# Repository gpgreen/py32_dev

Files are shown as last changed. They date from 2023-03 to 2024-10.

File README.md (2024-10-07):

# py32_dev

KiCad design for a ARM Cortex-M0+ development board. The MCU is a Puya
PY32 Series. The specific part is PY032F030K18T6. This can run at a
maximum of 48 MHz, and has 8 kbyte SRAM and 64 kbyte Flash. A USB C
connector provides 5V power only to the development board. The board
must be programmed with a debugger. External crystals are laid out for
the MCU to use a 32.768 kHz low speed crystal or a 24 MHz high speed
crystal. There is an onboard LDO that provides 500mA of power at
3.3V. A resettable fuse protects the USB port from a short. There is
an LED and push button connected to 2 of the GPIO pins. The value of
the BOOT0 pin can be set to ground or 3.3V permanently via the solder
bridge. A jumper can be used on the pin rails in lieue of the solder
bridge. All available GPIO pins are routed to the 2 18pin headers.

## Changes

- Rev B
  Moved resettable fuse away from USB C connector, giving more room to resolder
  connector pins.

- Rev A
  Original

## Firmware

Example firmware that blinks the LED. When the user pushbutton is pressed,
the frequency of the LED blink will change.

https://github.com/gpgreen/py32-dev-blink

## Boot configuration

To boot from main flash [0x0800_0000]
  Connect J2-4 to J2-5 (or) solder JP5-1 to center post

To boot from System mem [0x1FFF_0000], or Embedded SRAM [0x2000_0000]
  Connect J2-4 to J2-3 (or) solder JP6-3 to center post

There is an embedded boot loader, programmed in production, in the system memory
block. See the reference manual 3.6.2.

## PIN JUMPER SIGNAL ASSIGNMENT
```
                    +-----+
            +--------------------+
            |J3     |     |    J2|
        VDD-|1      +-----+     1|-GND
        GND-|2                  2|-GND
       +3.3-|3                  3|-+3.3
[RESET] PF2-|4                  4|-PF4 [BOOT0_PRE]
[SWCLK]PA14-|5                  5|-GND
[SWDIO]PA13-|6                  6|-GND
        GND-|7       RST        7|-GND
        PF3-|8       +-+        8|-GND
        PA0-|9       |O|        9|-GND
        PA1-|10      +-+       10|-PB7
        PA2-|11                11|-PB6
        PA3-|12                12|-PB5
        PA4-|13                13|-PB4
        PA6-|14                14|-PB3
        PA6-|15   UPB          15|-PA15
        PA7-|16   +-+          16|-PA12 [USER LED - GREEN]
        PB0-|17   |O|          17|-PA11 [USER PUSHBUTTON]
        PB1-|18   +-+          18|-PA8
            |                    |
            +--------------------+
```
## Connections to JTAG

From a 20pin JTAG connector, run wires to the following pins to connect a debugger:

VTRef 1  <-> J3-3
SWDIO 7  <-> J3-6
SWCLK 9  <-> J3-5
RESET 15 <-> J3-4
5V    19 <-> NC
GND   4  <-> J3-2
GND   20 <-> J3-7

## Running SEGGER JLink

Run the JLink GDB server via the following:
```
JLinkGDBServer -if SWD -JLinkDevicesXMLPath ~/.config/SEGGER/JLinkDevices/Puya/PY32/JLinkDevices.xml -device PY32F030xx8
```

GDB can be connected via the following:
```
gdb-multiarch --command=jlink-py32.gdb target/thumbv6m/debug/blink-py32
```

## Links
- [Puya PY32 Series](https://www.puyasemi.com/cpzx3/info_271_aid_247_kid_246.html)
- [Software template for PY32 Series by Jay Carlson](https://github.com/jaydcarlson/py32-template)
- [Fork of template for these boards](https://github.com/gpgreen/py32-dev-blink)
- [Tech documentation for py32f030](https://www.puyasemi.com/uploadfiles/2022/11/PY-MCU%E8%B5%84%E6%96%99-20221117.rar)

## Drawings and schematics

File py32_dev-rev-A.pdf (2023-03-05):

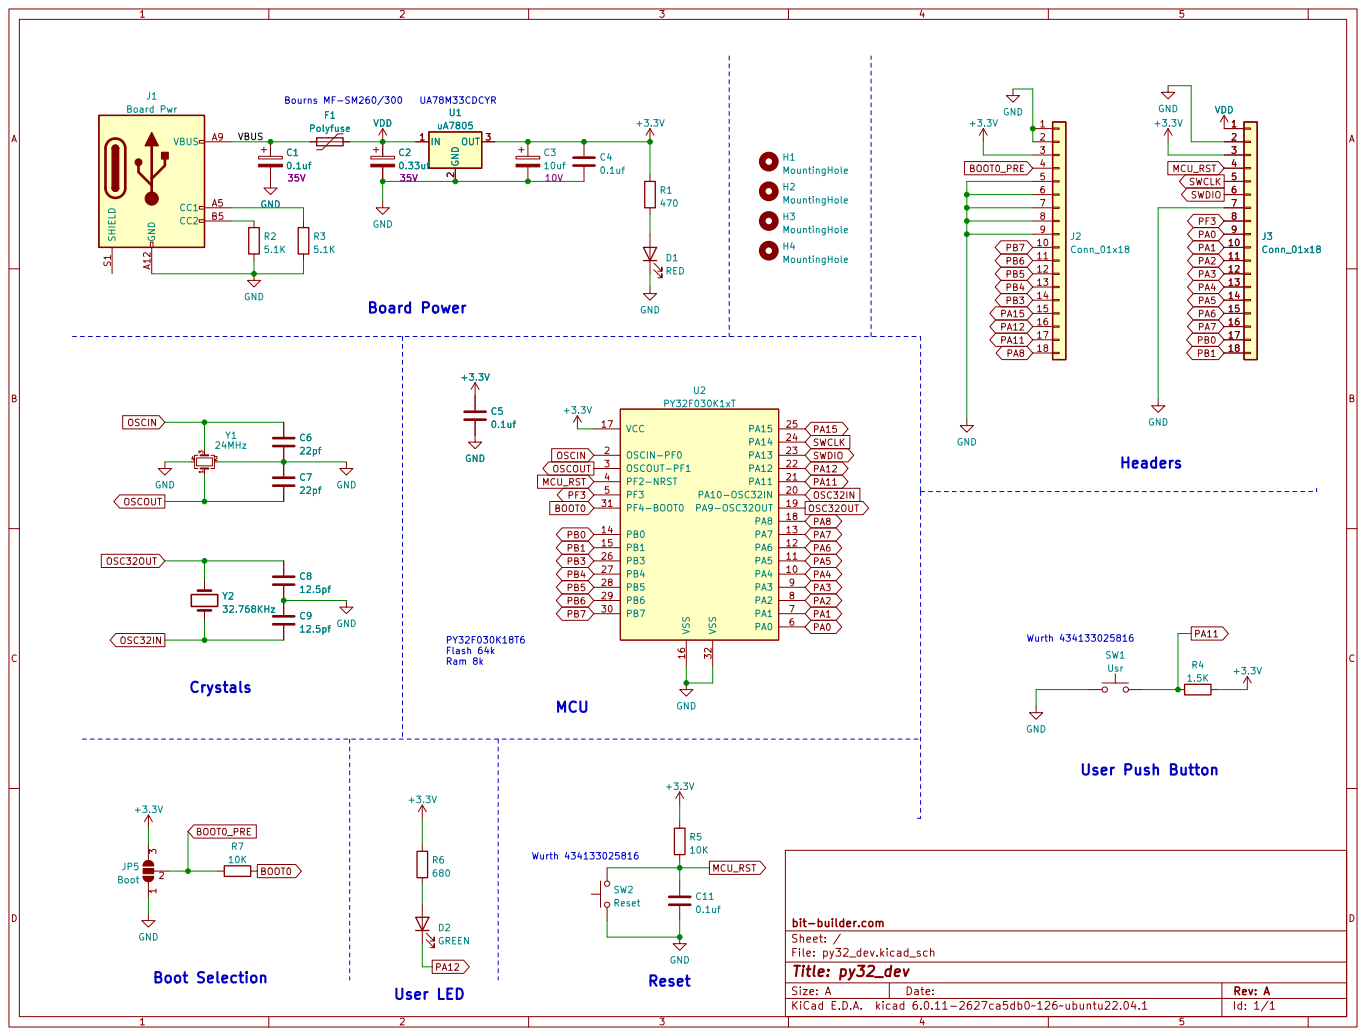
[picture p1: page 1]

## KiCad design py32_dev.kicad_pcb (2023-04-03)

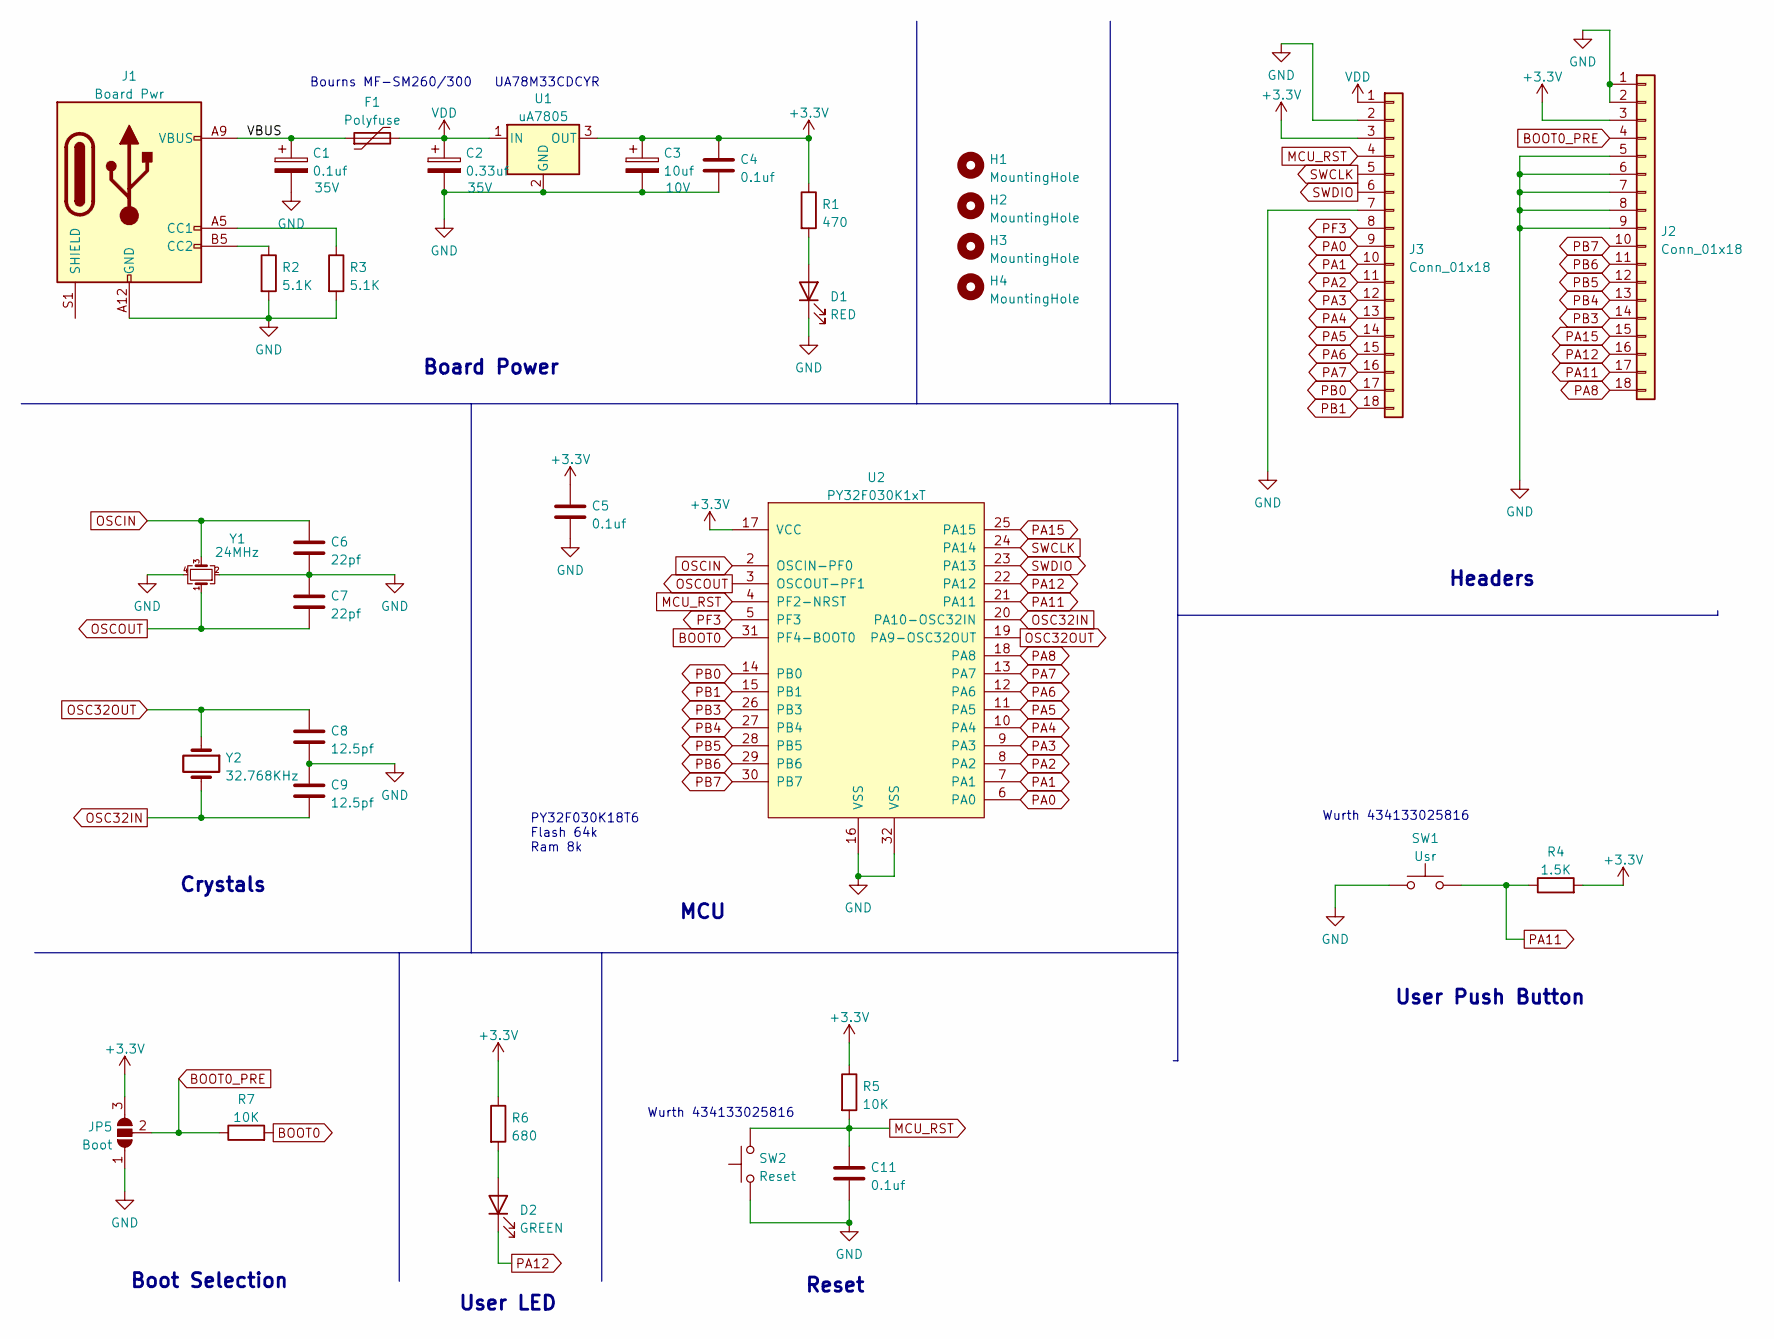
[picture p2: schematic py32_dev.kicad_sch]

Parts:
C1: 0.1uf; CP_EIA-3216-18_Kemet-A_Pad1.58x1.35mm_HandSolder; Voltage 35V
C2: 0.33uf; CP_EIA-3216-18_Kemet-A_Pad1.58x1.35mm_HandSolder; Voltage 35V
C3: 10uf; CP_EIA-3216-18_Kemet-A_Pad1.58x1.35mm_HandSolder; Voltage 10V
C4, C5, C11: 0.1uf; C_0603_1608Metric
C6, C7: 22pf; C_0603_1608Metric
C8, C9: 12.5pf; C_0603_1608Metric
D1: RED; D_0603_1608Metric
D2: GREEN; D_0603_1608Metric
F1: Polyfuse; Fuse_Bourns_MF-SM_7.98x5.44mm
H1, H2, H3, H4: MountingHole; MountingHole_2.5mm_Pad
J1: Board Pwr; SHOUHAN TYPE-C 6P
J2, J3: Conn_01x18; PinHeader_1x18_P2.54mm_Vertical
JP5: Boot; SolderJumper-3_P1.3mm_Open_Pad1.0x1.5mm_NumberLabels
R1: 470; R_0603_1608Metric
R2, R3: 5.1K; R_0603_1608Metric
R4: 1.5K; R_0603_1608Metric
R5, R7: 10K; R_0603_1608Metric
R6: 680; R_0603_1608Metric
SW1: Usr; SW_Push_1P1T_NO_Vertical_Wuerth_434133025816
SW2: Reset; SW_Push_1P1T_NO_Vertical_Wuerth_434133025816
U1: uA7805; SOT-223-3_TabPin2
U2: PY32F030K1xT; LQFP-32_7x7mm_P0.8mm
Y1: 24MHz; Crystal_SMD_TXC_7M-4Pin_3.2x2.5mm
Y2: 32.768KHz; Crystal_DS15_D1.5mm_L5.0mm_Horizontal

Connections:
+3.3V: C3.1, C4.1, C5.1, J2.3, J3.3, JP5.3 (B), R1.1, R4.2, R5.1, R6.1, U1.3 (OUT), U2.17 (VCC)
/VBUS: C1.1, F1.1, J1.A9 (VBUS), J1.B9 (VBUS)
BOOT0: R7.2, U2.31 (PF4-BOOT0)
BOOT0_PRE: J2.4, JP5.2 (C), R7.1
GND: C1.2, C2.2, C3.2, C4.2, C5.2, C6.2, C7.1, C8.2, C9.1, C11.2, D1.1 (K), J1.A12 (GND), J1.B12 (GND), J2.1, J2.2, J2.5, J2.6, J2.7, J2.8, J2.9, J3.2, J3.7, JP5.1 (A), R2.2, R3.2, SW1.1, SW2.1, U1.2 (GND), U2.16 (VSS), U2.32 (VSS), Y1.2, Y1.4
MCU_RST: C11.1, J3.4, R5.2, SW2.2, U2.4 (PF2-NRST)
unnamed: D1.2 (A), R1.2
unnamed: D2.2 (A), R6.2
unnamed: J1.A5 (CC1), R3.1
unnamed: J1.B5 (CC2), R2.1
OSC32IN: C9.2, U2.20 (PA10-OSC32IN), Y2.2
OSC32OUT: C8.1, U2.19 (PA9-OSC32OUT), Y2.1
OSCIN: C6.1, U2.2 (OSCIN-PF0), Y1.3
OSCOUT: C7.2, U2.3 (OSCOUT-PF1), Y1.1
PA0: J3.9, U2.6 (PA0)
PA1: J3.10, U2.7 (PA1)
PA2: J3.11, U2.8 (PA2)
PA3: J3.12, U2.9 (PA3)
PA4: J3.13, U2.10 (PA4)
PA5: J3.14, U2.11 (PA5)
PA6: J3.15, U2.12 (PA6)
PA7: J3.16, U2.13 (PA7)
PA8: J2.18, U2.18 (PA8)
PA11: J2.17, R4.1, SW1.2, U2.21 (PA11)
PA12: D2.1 (K), J2.16, U2.22 (PA12)
PA15: J2.15, U2.25 (PA15)
PB0: J3.17, U2.14 (PB0)
PB1: J3.18, U2.15 (PB1)
PB3: J2.14, U2.26 (PB3)
PB4: J2.13, U2.27 (PB4)
PB5: J2.12, U2.28 (PB5)
PB6: J2.11, U2.29 (PB6)
PB7: J2.10, U2.30 (PB7)
PF3: J3.8, U2.5 (PF3)
SWCLK: J3.5, U2.24 (PA14)
SWDIO: J3.6, U2.23 (PA13)
VDD: C2.1, F1.2, J3.1, U1.1 (IN)

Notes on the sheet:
Bourns MF-SM260/300
Wurth 434133025816
Headers
Boot Selection
Crystals
User Push Button
Reset
UA78M33CDCYR
MCU
PY32F030K18T6 Flash 64k Ram 8k
Board Power
User LED

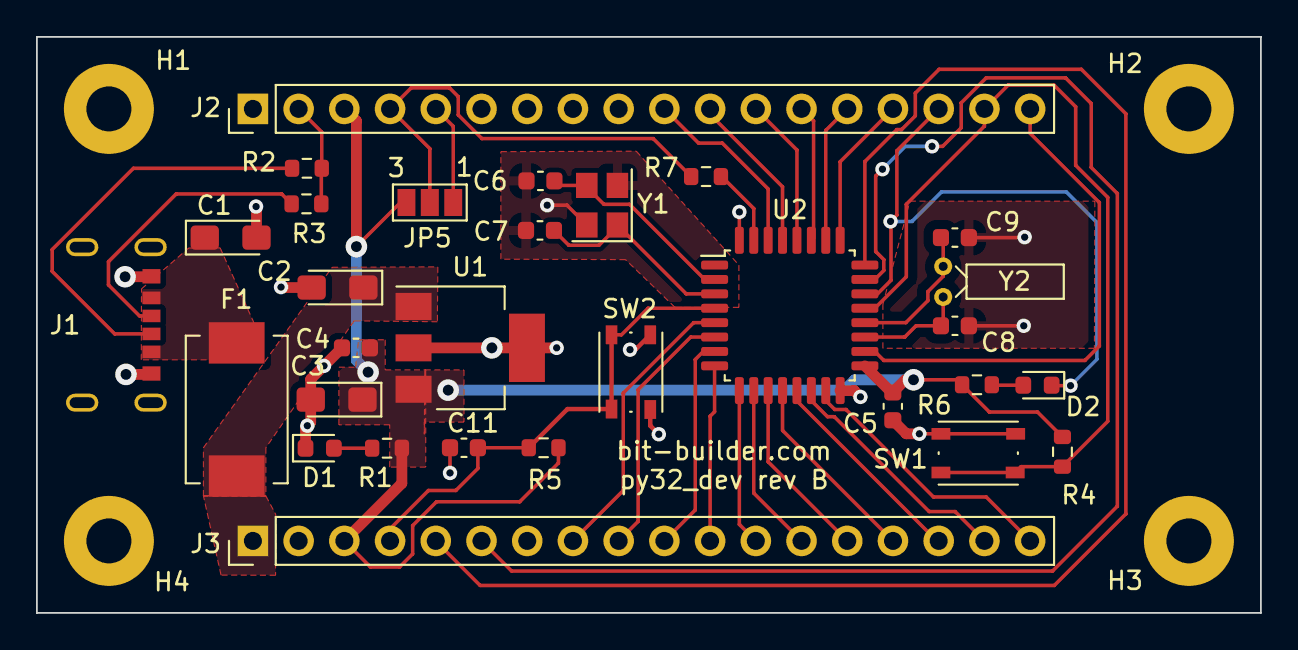
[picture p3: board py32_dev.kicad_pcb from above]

Board: 2 copper layers, 68.0 x 32.0 mm, 34 parts (0 on the bottom side), 37 nets.

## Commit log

2023-02-17 original design
    [py32_dev.kicad_pcb, py32_dev.kicad_sch]
2023-03-05 Added resistor values R2,R3
    [py32_dev.kicad_sch]
2023-03-05 Updated README and schematic pdf
2023-03-05 Updated revision to B
    Moved fuse slightly away from USB connector on the pcb for more room
    to resolder the USB connector pins
    [py32_dev.kicad_pcb, py32_dev.kicad_sch]
2023-03-07 Redid user pushbutton to work correctly
    [py32_dev.kicad_pcb, py32_dev.kicad_sch]
2023-04-03 Removed R4, user PB swap, back to rev A config
    Added link in README to blink firmware repository and puya32 tech docs
    [py32_dev.kicad_pcb, py32_dev.kicad_sch]
2024-10-07 Fixed pin labeling errors in README on J2
